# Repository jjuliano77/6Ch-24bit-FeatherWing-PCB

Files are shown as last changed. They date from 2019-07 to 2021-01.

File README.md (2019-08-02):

# 6Ch 24bit FeatherWing Design Files

This is a simple but versatile [Feather](https://learn.adafruit.com/adafruit-feather/feather-specification) compatible board. It uses an [AD7794](https://www.analog.com/media/en/technical-documentation/data-sheets/AD7794_7795.pdf), a very robust 6 channel 24 bit ADC. It's a relatively slow converter (470 Hz Max), but this board is really suited for lower power, monitoring type applications and can consume as little as 2 μA in standby. It has an on-board 2.5 V regulator for excitation voltage and is designed primarily to read load cells and pressure gauges. However, it can also be used to read any ratiometric sensor (such as potentiometers), thermocouples, or any 0 - 3.3 V signal.

**Specifications**

- RMS noise down to 40 nV at lowest data rate (4.17 Hz)
- Power-down current: 1 μA maximum (AD7794 chip) 
- Low noise, programmable gain, instrumentation amplifier
- Band gap reference with 4 ppm/°C drift typical
- Simultaneous 50 Hz/60 Hz rejection
- Update rate: 4.17 Hz to 470 Hz
- Six differential analog inputs
- 4 pin connections with excitation and ground for each channel
- On board 2.5v LDO with enable pin broken out to turn off excitation for low power applications

The board can be used with screw terminals, Plug in spring terminal connectors, or pin headers for the sensor connections

This board can be purchased assembled here: [6-ch-24-bit-full-bridge-sensor-featherwing](https://www.tindie.com/products/jtinker/6-ch-24-bit-full-bridge-sensor-featherwing/)



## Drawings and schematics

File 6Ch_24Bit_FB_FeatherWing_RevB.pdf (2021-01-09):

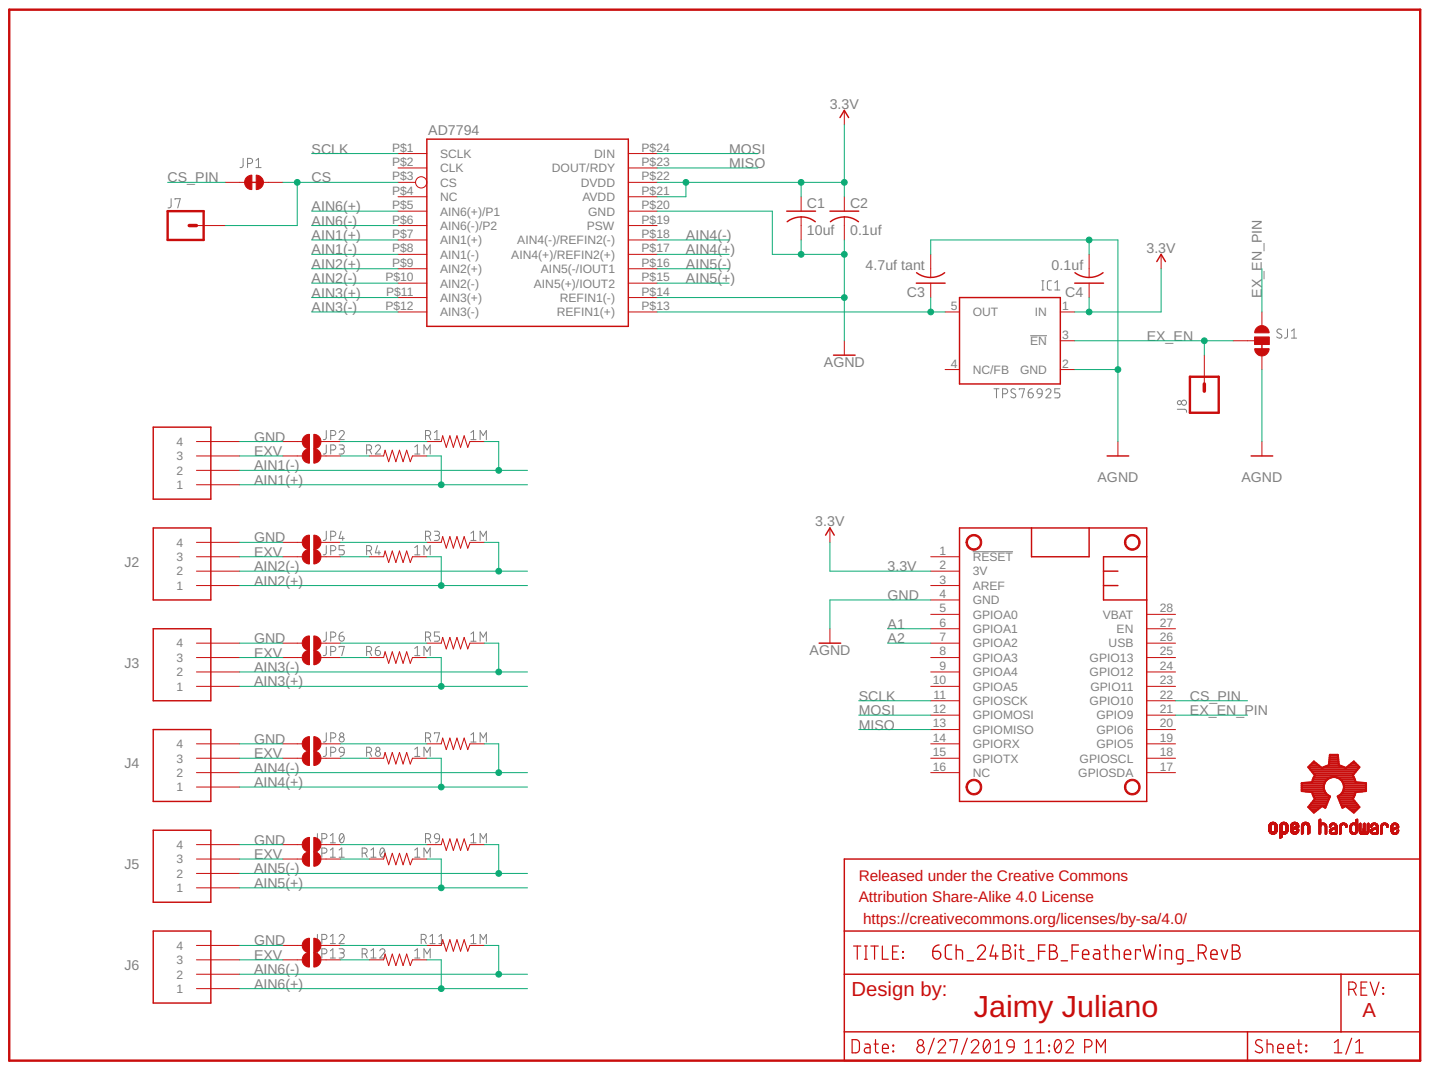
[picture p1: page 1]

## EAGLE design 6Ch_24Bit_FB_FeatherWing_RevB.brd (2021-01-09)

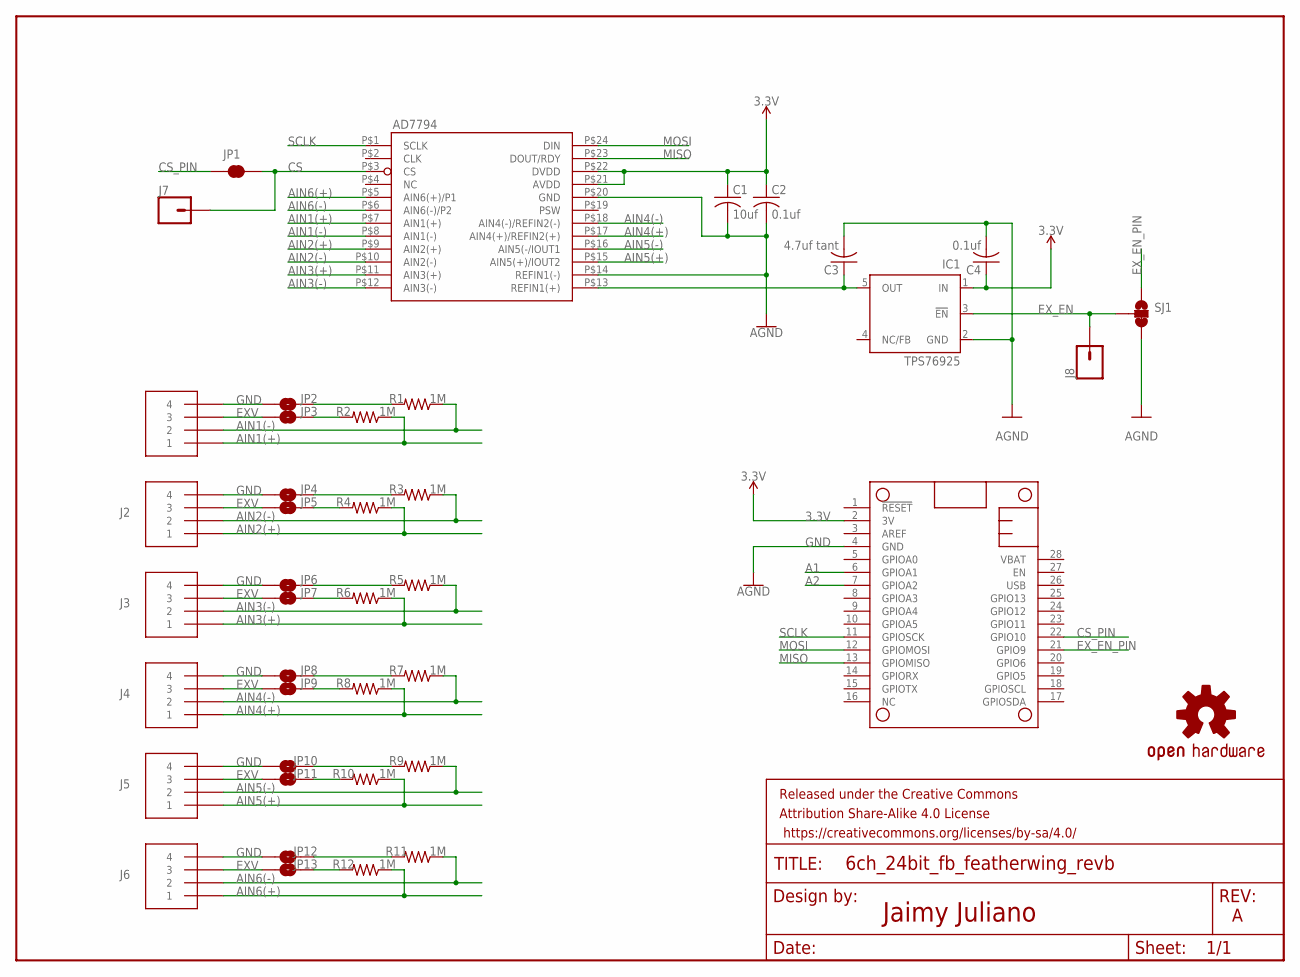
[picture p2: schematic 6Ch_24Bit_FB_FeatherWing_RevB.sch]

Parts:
C1: 10uf; C0603
C2, C4: 0.1uf; C0603
C3: 4.7uf tant; C1206K
FRAME2: FRAME-LETTER; CREATIVE_COMMONS
IC1: TPS76925; SOT23-DBV
J1, J2, J3, J4, J5, J6: CON_PTSM_SOCKET-4-PTH-VERT
J7, J8: CONN_01PTH_NO_SILK_YES_STOP; 1X01_NO_SILK
JP1: JUMPER-SMT_2_NC_TRACE_NO-SILK; SMT-JUMPER_2_NC_TRACE_NO-SILK
JP2, JP3, JP4, JP5, JP6, JP7, JP8, JP9, JP10, JP11, JP12, JP13: JUMPER-SMT_2_NO_SILK; SMT-JUMPER_2_NO_SILK
LOGO1: OSHW-LOGOS; OSHW-LOGO-S
MS1: FEATHERWING_NODIM; FEATHERWING_DIM
R1, R2, R3, R4, R5, R6, R7, R8, R9, R10, R11, R12: 1M; 0603
SJ1: JUMPER-SMT_3_1-NC_TRACE_NO-SILK; SMT-JUMPER_3_1-NC_TRACE_NO-SILK
U1: AD7794; TSSOP-24

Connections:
3.3V: C1.1, C2.1, C4.1, IC1.1 (IN), MS1.2 (3V), U1.P$21 (AVDD), U1.P$22 (DVDD)
A1: MS1.6 (GPIOA1)
A2: MS1.7 (GPIOA2)
AIN1(+): J1.P$1 (1), R2.1, U1.P$7 (AIN1(+))
AIN1(-): J1.P$2 (2), R1.1, U1.P$8 (AIN1(-))
AIN2(+): J2.P$1 (1), R4.1, U1.P$9 (AIN2(+))
AIN2(-): J2.P$2 (2), R3.1, U1.P$10 (AIN2(-))
AIN3(+): J3.P$1 (1), R6.1, U1.P$11 (AIN3(+))
AIN3(-): J3.P$2 (2), R5.1, U1.P$12 (AIN3(-))
AIN4(+): J4.P$1 (1), R8.1, U1.P$17 (AIN4(+)/REFIN2(+))
AIN4(-): J4.P$2 (2), R7.1, U1.P$18 (AIN4(-)/REFIN2(-))
AIN5(+): J5.P$1 (1), R10.1, U1.P$15 (AIN5(+)/IOUT2)
AIN5(-): J5.P$2 (2), R9.1, U1.P$16 (AIN5(-/IOUT1)
AIN6(+): J6.P$1 (1), R12.1, U1.P$5 (AIN6(+)/P1)
AIN6(-): J6.P$2 (2), R11.1, U1.P$6 (AIN6(-)/P2)
CS: J7.1, JP1.2, U1.P$3 (CS)
CS_PIN: JP1.1, MS1.22 (GPIO10)
EXV: C3.1, IC1.5 (OUT), J1.P$3 (3), J2.P$3 (3), J3.P$3 (3), J4.P$3 (3), J5.P$3 (3), J6.P$3 (3), JP3.2, JP5.2, JP7.2, JP9.2, JP11.2, JP13.2, U1.P$13 (REFIN1(+))
EX_EN: IC1.3 (!EN), J8.1, SJ1.2
EX_EN_PIN: MS1.21 (GPIO9), SJ1.1
GND: C1.2, C2.2, C3.2, C4.2, IC1.2 (GND), J1.P$4 (4), J2.P$4 (4), J3.P$4 (4), J4.P$4 (4), J5.P$4 (4), J6.P$4 (4), JP2.2, JP4.2, JP6.2, JP8.2, JP10.2, JP12.2, MS1.4 (GND), SJ1.3, U1.P$14 (REFIN1(-)), U1.P$20 (GND)
MISO: MS1.13 (GPIOMISO), U1.P$23 (DOUT/RDY)
MOSI: MS1.12 (GPIOMOSI), U1.P$24 (DIN)
unnamed: JP3.1, R2.2
unnamed: JP2.1, R1.2
unnamed: JP5.1, R4.2
unnamed: JP4.1, R3.2
unnamed: JP7.1, R6.2
unnamed: JP6.1, R5.2
unnamed: JP9.1, R8.2
unnamed: JP8.1, R7.2
unnamed: JP11.1, R10.2
unnamed: JP10.1, R9.2
unnamed: JP13.1, R12.2
unnamed: JP12.1, R11.2
SCLK: MS1.11 (GPIOSCK), U1.P$1 (SCLK)

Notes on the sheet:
Jaimy Juliano

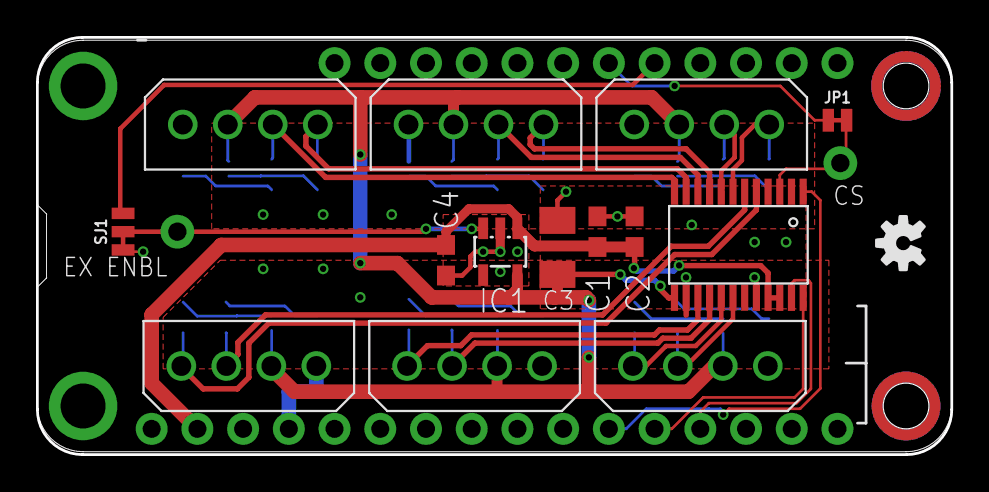
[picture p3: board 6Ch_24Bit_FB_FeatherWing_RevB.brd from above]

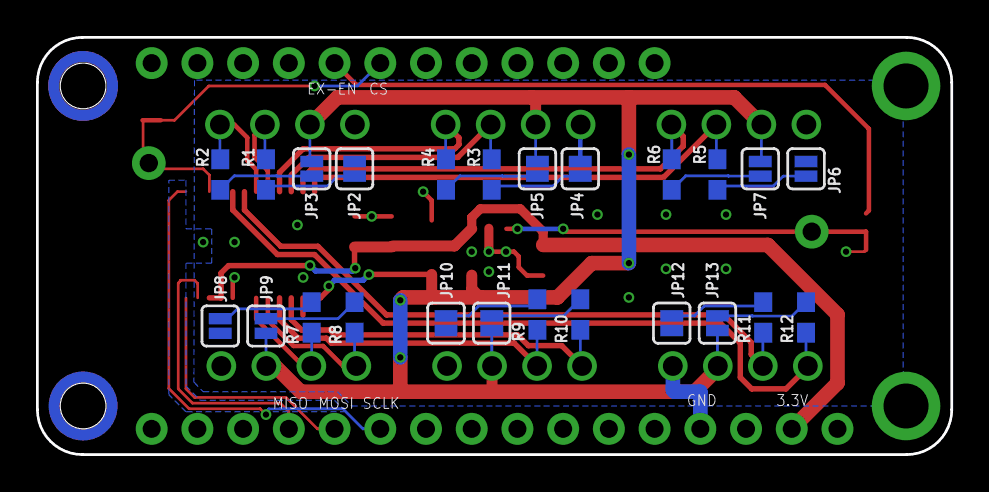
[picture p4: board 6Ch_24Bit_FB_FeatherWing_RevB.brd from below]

Board: 2 copper layers, 50.8 x 23.2 mm, 43 parts (24 on the bottom side), 34 nets.

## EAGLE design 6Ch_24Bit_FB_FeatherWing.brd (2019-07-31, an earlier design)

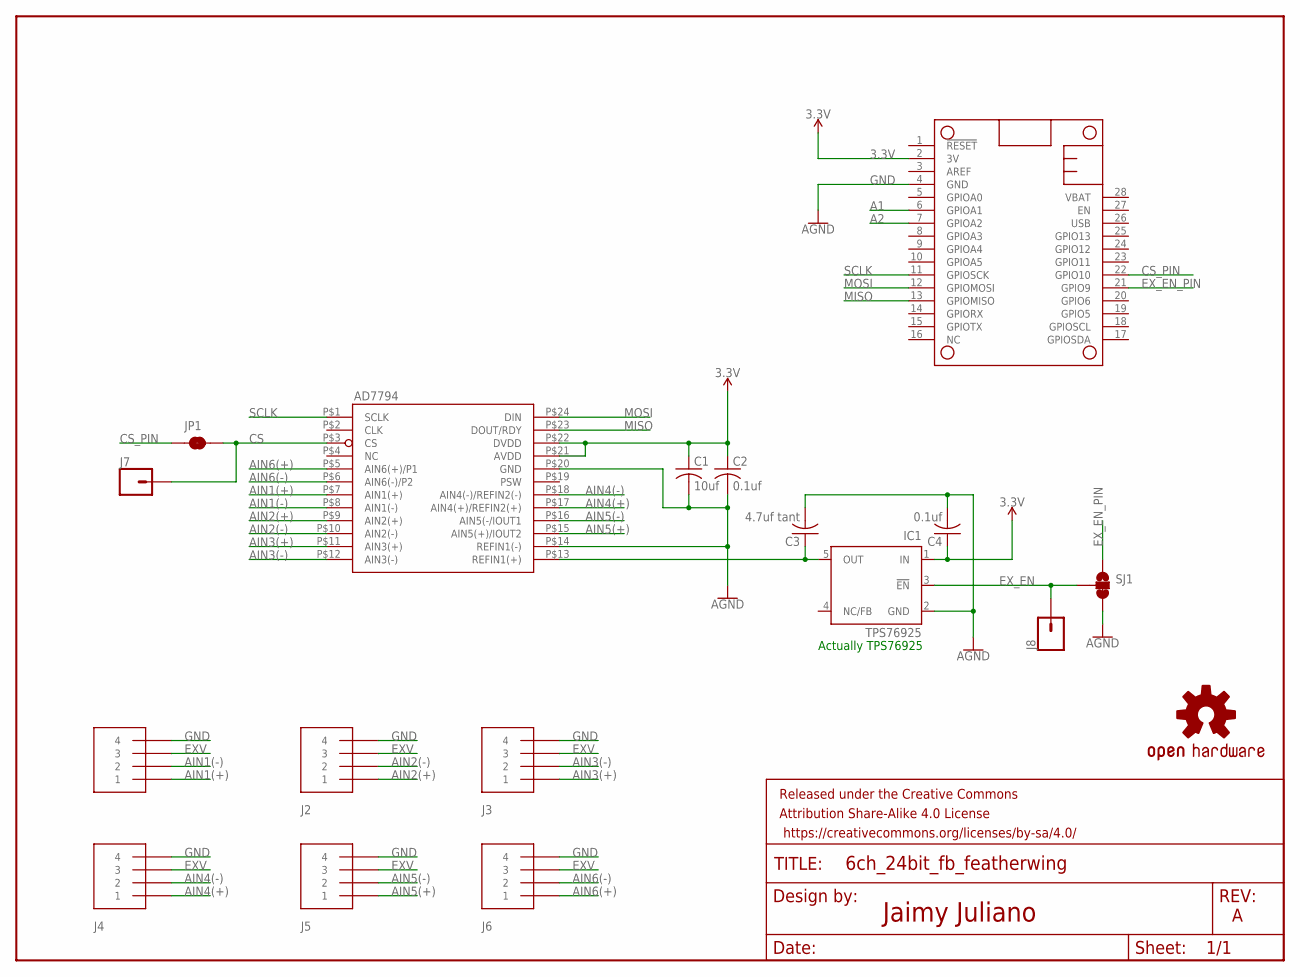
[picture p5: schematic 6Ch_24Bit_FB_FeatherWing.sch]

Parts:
C1: 10uf; C0603
C2, C4: 0.1uf; C0603
C3: 4.7uf tant; C1206K
FRAME2: FRAME-LETTER; CREATIVE_COMMONS
IC1: TPS76925; SOT23-DBV
J1, J2, J3, J4, J5, J6: CON_PTSM_SOCKET-4-PTH-VERT
J7, J8: CONN_01PTH_NO_SILK_YES_STOP; 1X01_NO_SILK
JP1: JUMPER-SMT_2_NC_TRACE_NO-SILK; SMT-JUMPER_2_NC_TRACE_NO-SILK
LOGO1: OSHW-LOGOS; OSHW-LOGO-S
MS1: FEATHERWING_NODIM; FEATHERWING_DIM
SJ1: JUMPER-SMT_3_1-NC_TRACE_NO-SILK; SMT-JUMPER_3_1-NC_TRACE_NO-SILK
U1: AD7794; TSSOP-24

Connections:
3.3V: C1.1, C2.1, C4.1, IC1.1 (IN), MS1.2 (3V), U1.P$21 (AVDD), U1.P$22 (DVDD)
A1: MS1.6 (GPIOA1)
A2: MS1.7 (GPIOA2)
AIN1(+): J1.P$1 (1), U1.P$7 (AIN1(+))
AIN1(-): J1.P$2 (2), U1.P$8 (AIN1(-))
AIN2(+): J2.P$1 (1), U1.P$9 (AIN2(+))
AIN2(-): J2.P$2 (2), U1.P$10 (AIN2(-))
AIN3(+): J3.P$1 (1), U1.P$11 (AIN3(+))
AIN3(-): J3.P$2 (2), U1.P$12 (AIN3(-))
AIN4(+): J4.P$1 (1), U1.P$17 (AIN4(+)/REFIN2(+))
AIN4(-): J4.P$2 (2), U1.P$18 (AIN4(-)/REFIN2(-))
AIN5(+): J5.P$1 (1), U1.P$15 (AIN5(+)/IOUT2)
AIN5(-): J5.P$2 (2), U1.P$16 (AIN5(-/IOUT1)
AIN6(+): J6.P$1 (1), U1.P$5 (AIN6(+)/P1)
AIN6(-): J6.P$2 (2), U1.P$6 (AIN6(-)/P2)
CS: J7.1, JP1.2, U1.P$3 (CS)
CS_PIN: JP1.1, MS1.22 (GPIO10)
EXV: C3.1, IC1.5 (OUT), J1.P$3 (3), J2.P$3 (3), J3.P$3 (3), J4.P$3 (3), J5.P$3 (3), J6.P$3 (3), U1.P$13 (REFIN1(+))
EX_EN: IC1.3 (!EN), J8.1, SJ1.2
EX_EN_PIN: MS1.21 (GPIO9), SJ1.1
GND: C1.2, C2.2, C3.2, C4.2, IC1.2 (GND), J1.P$4 (4), J2.P$4 (4), J3.P$4 (4), J4.P$4 (4), J5.P$4 (4), J6.P$4 (4), MS1.4 (GND), SJ1.3, U1.P$14 (REFIN1(-)), U1.P$20 (GND)
MISO: MS1.13 (GPIOMISO), U1.P$23 (DOUT/RDY)
MOSI: MS1.12 (GPIOMOSI), U1.P$24 (DIN)
SCLK: MS1.11 (GPIOSCK), U1.P$1 (SCLK)

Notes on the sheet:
Actually TPS76925
Jaimy Juliano

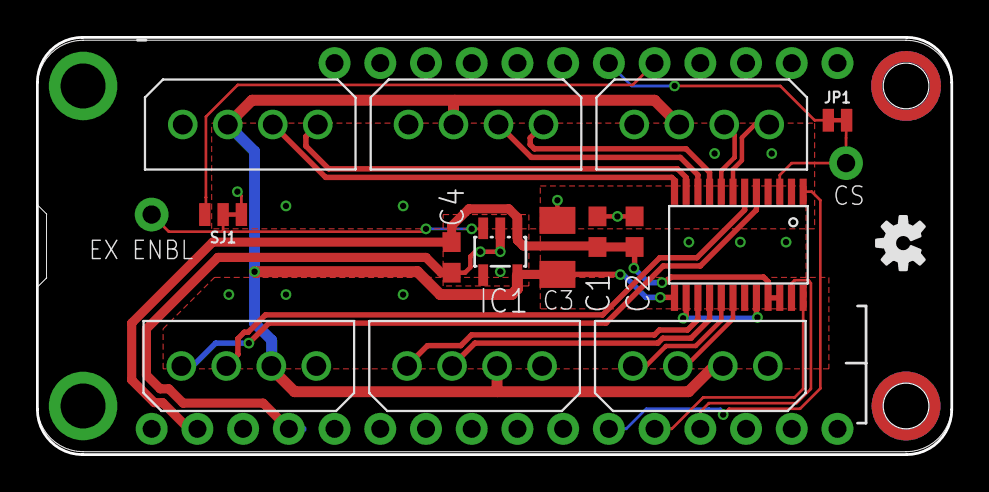
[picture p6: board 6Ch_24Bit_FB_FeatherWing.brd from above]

Board: 2 copper layers, 50.8 x 23.2 mm, 19 parts (0 on the bottom side), 22 nets.

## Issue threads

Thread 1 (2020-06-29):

Add pins / terminals for load cell's shield

ClemensGruber, 2020-06-29:
I would recommend to replace the 4 pin terminals with 5 pin terminals. Every better load cell has a shielded cable and measuring is more stabel if the shield is connected to GND. So it would be fantastic if this board would have an opportunity to connect the load cell's shild to the board / GND also!

jjuliano77, 2020-07-08:
Thanks for your input.

There isn't really enough room to do it properly for 6 channels on a
Feather format board.  I figured you can always share the GND connection
with the shield wire and the GND wire. (Of course technically speaking, the
shield really should be connected to an enclosure or chassis, not just to
the same ground.)  Anyway, I understand that it might be convenient to have
all the wires terminate neatly at a 5 pin connection.  I have been working
on a 4 channel board with a different (and faster) chip. On that board
there is just enough room to squeeze in a 5th pin for a shield connection,
so I decided to give it a try. I was also able to give the shield an
independent ground pour, which can either be connected to AGND with a
jumper, or wired to an enclosure/chassis ground. I have to get the boards
built and do a lot of testing, but I do have something new coming up.

On Mon, Jun 29, 2020 at 1:46 PM ClemensGruber <notifications@github.com>
wrote:

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

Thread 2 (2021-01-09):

Update files to the version selled in tindie

martincolladofab, 2021-01-09:
Looks like the schematics not reflects the changes made to support the thermocouples and the 1 MOhm bias resistors to the bottom of the board

jjuliano77, 2021-01-09:
Done

Closed 2021-01-09.

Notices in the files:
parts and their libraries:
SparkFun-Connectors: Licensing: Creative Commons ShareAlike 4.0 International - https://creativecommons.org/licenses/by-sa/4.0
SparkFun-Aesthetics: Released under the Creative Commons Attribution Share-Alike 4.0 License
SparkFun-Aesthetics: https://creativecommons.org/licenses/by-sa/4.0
